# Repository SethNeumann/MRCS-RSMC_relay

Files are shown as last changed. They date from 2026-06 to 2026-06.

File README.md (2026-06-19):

# REPO NAME: MRCS-RSMC_relay
## License: Creative Commons Attribution-NonCommercial-ShareAlike

Chuck Catania created the Remote Stall Motor Controller for CMRi and cpNode systems to make a single board controller for
common stall motor functions: 
drive (reverse 12V DC to steer the motor) 
Break out Frog power using heavy traces and a 3 position 3.5mm connector
used the second contact to provide power and limiting resistors for indicator LEDs on a panel or dwarf signal 
This board replaces the TC4428 with a DPDT relay to provide a full metallic connection to avoid sneak paths in the FETs.

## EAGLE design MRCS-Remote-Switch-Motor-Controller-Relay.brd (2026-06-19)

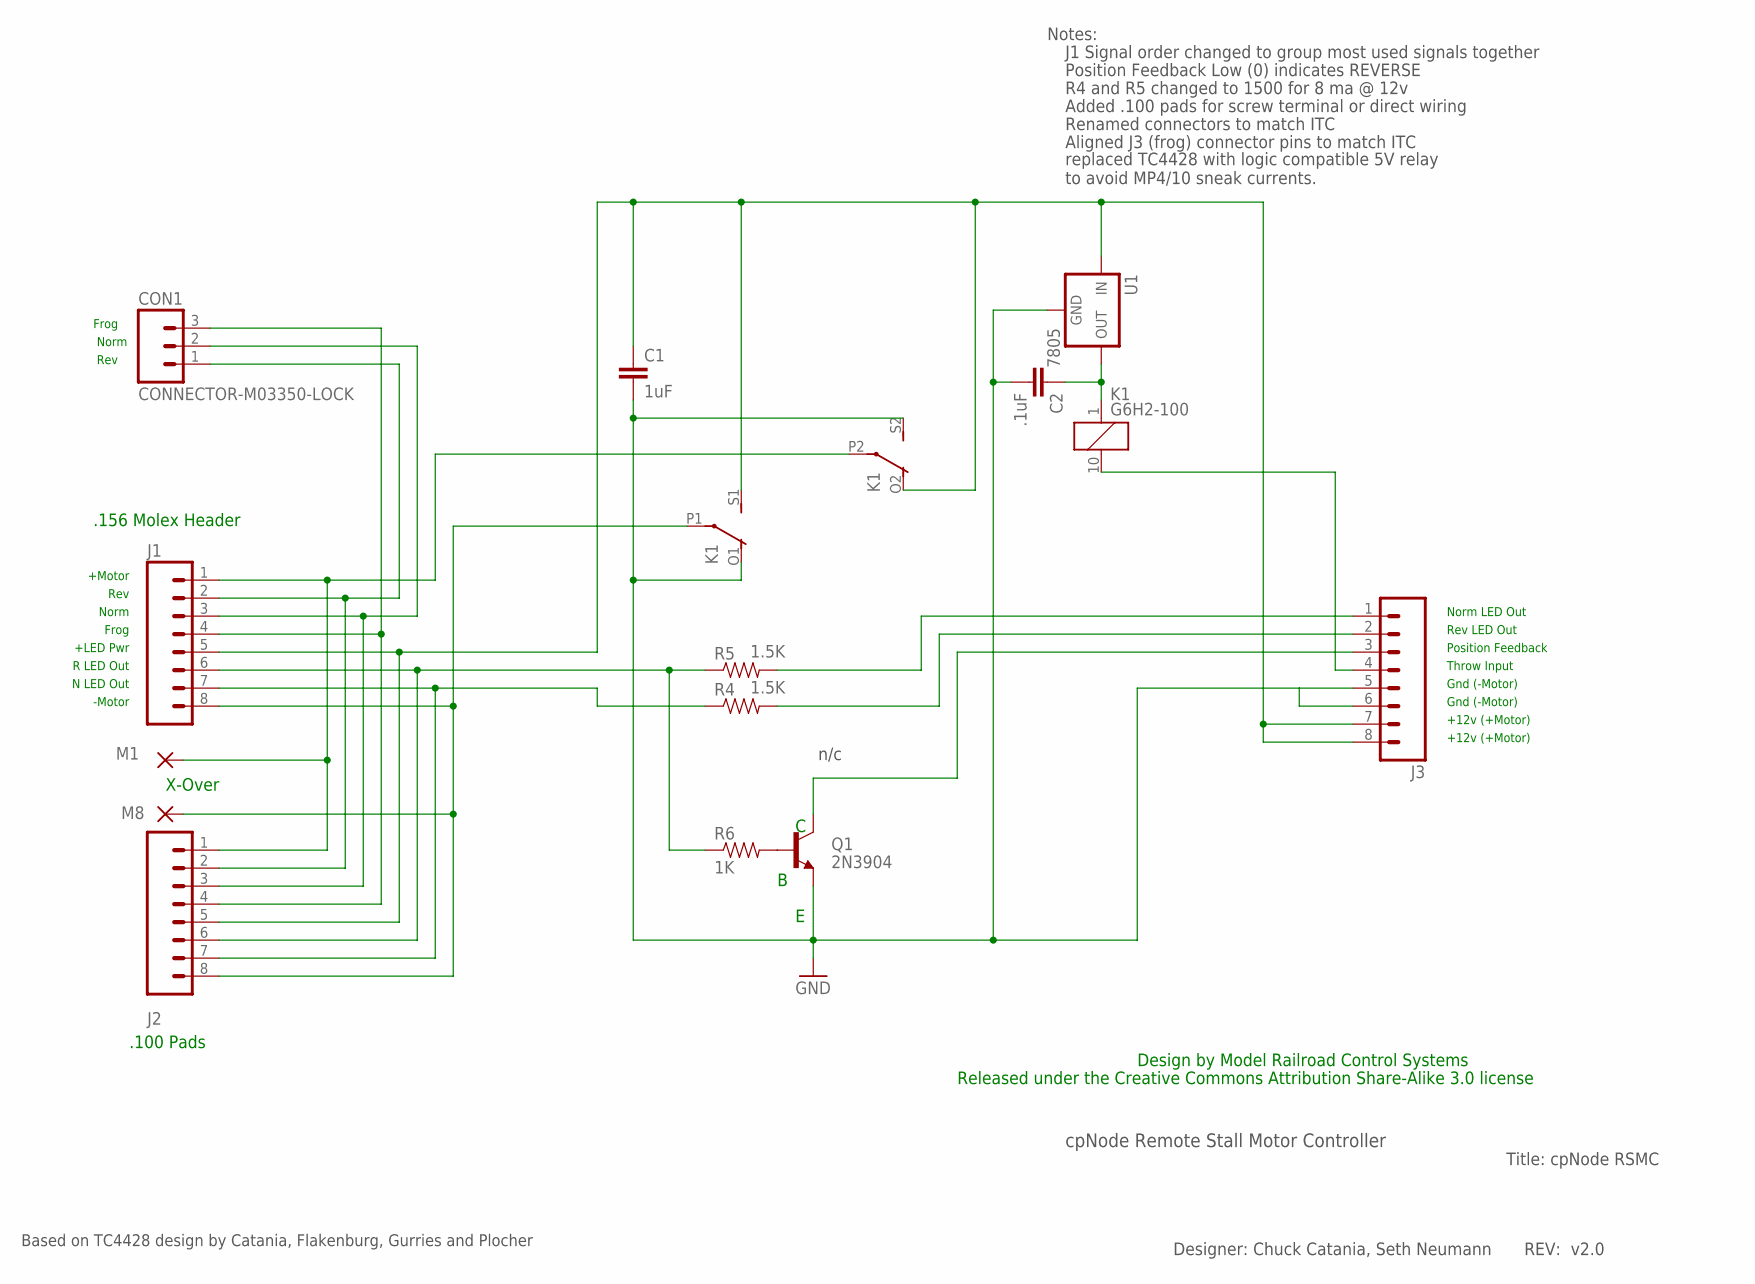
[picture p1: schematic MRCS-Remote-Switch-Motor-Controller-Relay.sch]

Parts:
C1: 1uF; CAP-PTH-SMALLEZ
C2: .1uF; CAP-PTH-SMALLEZ
CON1: CONNECTOR-M03350-LOCK; 1751251
J1: J1; KK-156-8-F
J2: J2; 1X08_PIN1_NO_SILK
J3: CONNECTOR-M08LOCK; 1X08_LOCK
K1: G6H2-100
M1, M8: WIREPAD2,54/1,1; 2,54/1,1
Q1: 2N3904; TO-92-MS013
R4, R5: 1.5K; AXIAL-0.4-RES
R6: 1K; AXIAL-0.4-RES
U1: 7805; TO92D-

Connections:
+5: C2.1, K1.1, U1.3 (VOUT)
+12: C1.1, J1.5, J2.5, J3.7, J3.8, K1.O2 (O), K1.S1 (S), U1.1 (VIN)
FROG: CON1.3, J1.4, J2.4
GND: C1.2, C2.2, J3.5, J3.6, K1.O1 (O), K1.S2 (S), Q1.1 (E), U1.2 (GND)
M1: J1.1, J2.1, K1.P2, M1.1
M8: J1.8, J2.8, K1.P1, M8.1
unnamed: J3.3, Q1.3 (C)
unnamed: J3.2, R4.P$2 (2)
unnamed: Q1.2 (B), R6.P$2 (2)
unnamed: J3.1, R5.P$2 (2)
N-LED: J1.7, J2.7, R4.P$1 (1)
NORM: CON1.2, J1.3, J2.3
R-LED: J1.6, J2.6, R5.P$1 (1), R6.P$1 (1)
REV: CON1.1, J1.2, J2.2
THROW: J3.4, K1.10 (2)

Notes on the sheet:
Norm
Rev
+12v (+Motor)
Gnd (-Motor)
Norm LED Out
Rev LED Out
Frog
+Motor
-Motor
Throw Input
+LED Pwr
R LED Out
N LED Out
.156 Molex Header
Position Feedback
cpNode Remote Stall Motor Controller
Title: cpNode RSMC
Designer: Chuck Catania, Seth Neumann
REV: v2.0
n/c
Based on TC4428 design by Catania, Flakenburg, Gurries and Plocher
Notes:
Position Feedback Low (0) indicates REVERSE
R4 and R5 changed to 1500 for 8 ma @ 12v
J1 Signal order changed to group most used signals together
Frog
.100 Pads
Added .100 pads for screw terminal or direct wiring
X-Over
Renamed connectors to match ITC
Aligned J3 (frog) connector pins to match ITC
Released under the Creative Commons Attribution Share-Alike 3.0 license
Design by Model Railroad Control Systems
replaced TC4428 with logic compatible 5V relay to avoid MP4/10 sneak currents.

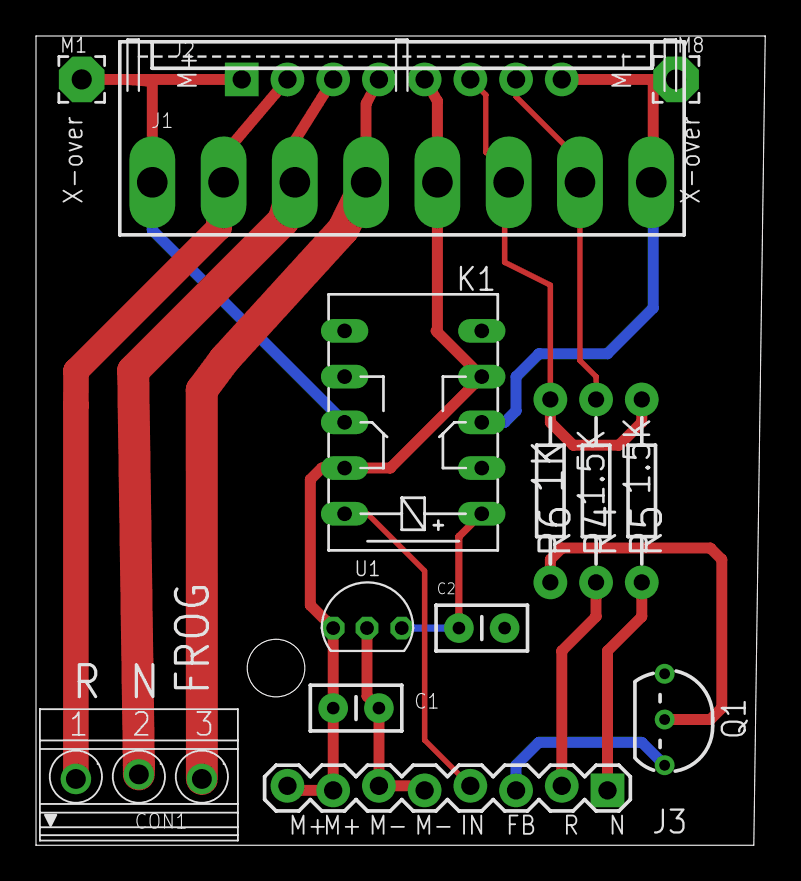
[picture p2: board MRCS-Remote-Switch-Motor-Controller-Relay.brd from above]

Board: 2 copper layers, 40.5 x 45.0 mm, 16 parts (0 on the bottom side), 15 nets.

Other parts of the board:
U$1: MRCSLOGOBTM
U$2: CA-PROP65WARNING

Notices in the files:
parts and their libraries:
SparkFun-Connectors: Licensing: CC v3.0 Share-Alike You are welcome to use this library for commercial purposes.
